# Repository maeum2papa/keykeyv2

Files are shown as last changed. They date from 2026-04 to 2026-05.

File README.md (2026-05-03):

# keykeyv2 제작 가이드

---

## 개발 계기
손목 터널 증후군 통증을 완화하기 위한 목적으로 개발
- 손목이 들리거나 꺽이는 걸 방지하기 위해 낮은 키보드를 사용
- 손목의 자연스러운 형태를 유지하기 위해 반으로 자름
- 개발자 주로 사용하는 키를 서로 가깝게 배치

---

## 키보드 특징

- **스플릿 키보드** (좌/우 분리형)
- **각 사이드 5행 6열** = 총 60키 (매트릭스)
- **왼쪽 사이드가 마스터**
- **방향키 4개**(다이렉트 핀, 5방향 네비게이션 스위치)
- **캡스락 LED** 1개
- **Vial-QMK** 사용 (GUI로 키맵 변경 가능)

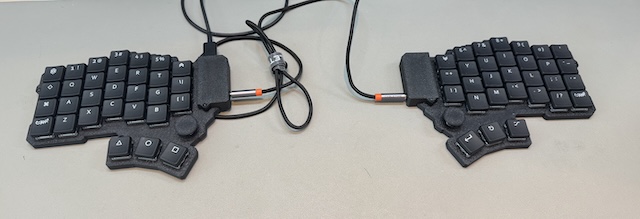
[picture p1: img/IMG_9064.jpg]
keykeyv2


---

## 필요 부품

### 🔲 프로세서
| 항목 | 수량 | 상세 |
|---|---|---|
| RP2040-Zero | 2개 | 좌/우 각 1개. 옆면 캐스텔레이티드(Castellated) 핀 납땜 계획. USB-C 내장 |

> ⚠️ 반드시 정품 구매

### ⌨️ 스위치 & 소켓
| 항목 | 수량 | 상세 |
|---|---|---|
| Kailh Choc v1 (1350) 스위치 | 60개 | 
| Choc v1 전용 핫스왑 소켓 | 60개 | 반드시 Choc v1 전용 규격 확인 (MX 소켓과 호환 안됨) |

### 🔵 다이오드
| 항목 | 수량 | 상세 |
|---|---|---|
| 1N4148W SMD 다이오드 | 60개 |

### 🕹️ 방향키 & 인코더
| 항목 | 수량 | 상세 |
|---|---|---|
| 5-Way 네비게이션 스위치 | 1개 | 상/하/좌/우/센터 클릭 지원 모델. PCB에 45도 회전 배치 권장 |

> ⚠️ 5방향 스위치를 정사각형으로 배치하면 대각 방향으로 눌러야 상하좌우 동작함.
> PCB 설계 시 반드시 **45도 회전(마름모) 배치** 권장

### 💡 상태 표시 LED
| 항목 | 수량 | 상세 |
|---|---|---|
| 3mm LED | 2개 | 각 사이드 1개. Caps Lock 활성 표시용 |
| 저항 330Ω | 2개 | LED 보호용. 각 사이드 GP28과 LED 사이에 직렬 연결 |

### 🔌 통신 & 연결
| 항목 | 수량 | 상세 |
|---|---|---|
| PJ-320A TRRS 잭 | 2개 | 반드시 4극 전용 (3극 사용 시 쇼트 위험) |
| 4극 TRRS 케이블 | 1개 | 양쪽 유선 연결용 |
| 저항 1kΩ | 2개 | GP0 ↔ TRRS Ring 사이 각 사이드 1개씩 (통신 보호용) |

---

## PCB 주문 제작
샘플 PCB를 제작 해주는 곳에서는 어디서든 가능 (JLC PCB, 샘플 PCB ...)

### 1. 거버 및 드릴 파일 다운로드
/last/keykeyv2.1_l.zip (왼쪽)
/last/keykeyv2.1_r.zip (오른쪽)

### 2. PCB 주문
keykeyv2.1_l.zip, keykeyv2.1_r.zip 파일을 업로드해서 주문

---

## 납땜

### 1. 납땜 위치
- 다이오드, 핫스왑 소켓 후면에 장착
- RP2024-zero, PJ-320A TRRS 잭, LED 앞면 장착

### 2. 다이오드 방향
- (|) 표시가 있는 방향이 양 사이드의 가운데를 향해야 함 (왼쪽 사이드에서는 오른쪽, 오른쪽 사이드에서는 왼쪽)

---

## 필요 프로그램 설치

### 1. 파일 다운로드
/last/keykeyv2_vial.uf2 다운로드

### 2. 각 사이드 마다 RP2024-zero 펌웨어 업로드
- 1. 모든 선 분리 후 USB만 단독으로 연결 (꼭 통신 케이블용 사용)
- 1. BOOT 버튼, RESET 버튼 동시에 누름
- 2. 1초 후 RESET 버튼에서 손때고 그 다음 1초 후 BOOT 버튼에서 손 땜
- 3. 외장 드라이버로 인식되면 keykeyv2_vial.uf2 파일 복사해서 저장
- 4. 자동으로 RP2024-zero 재부팅

---

## 작동 테스트

- 1. USB가 연결되지 않은 상태에서 TRRS선 연결
> ⚠️ USB가 연결된 상태에서 TRRS선 분리하면 고장남
- 2. USB 왼쪽 사이드에 연결
> 항상 왼쪽이 마스터

---

## 3D 프린터를 이용한 케이스 출력
/last/keykeyv2_case.3mf 다운로드 하여 출력

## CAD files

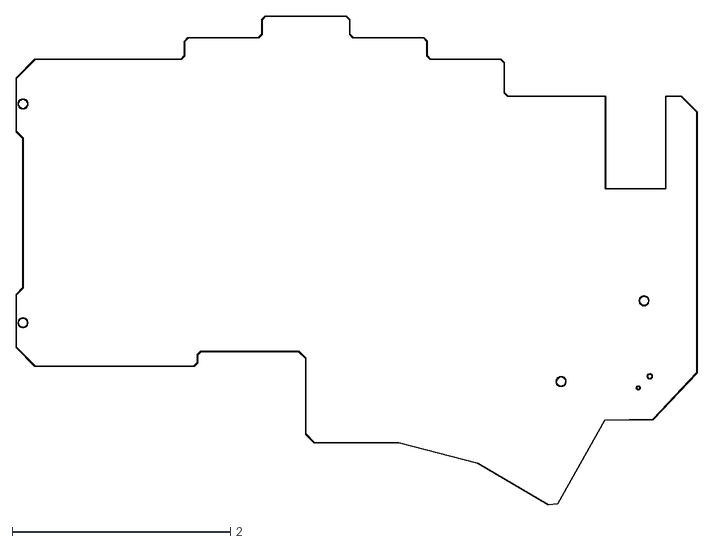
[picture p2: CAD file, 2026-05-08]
hardware/keykeyv2.1/print/keykeyv2.1-Edge_Cuts.dxf
6.24 x 4.48

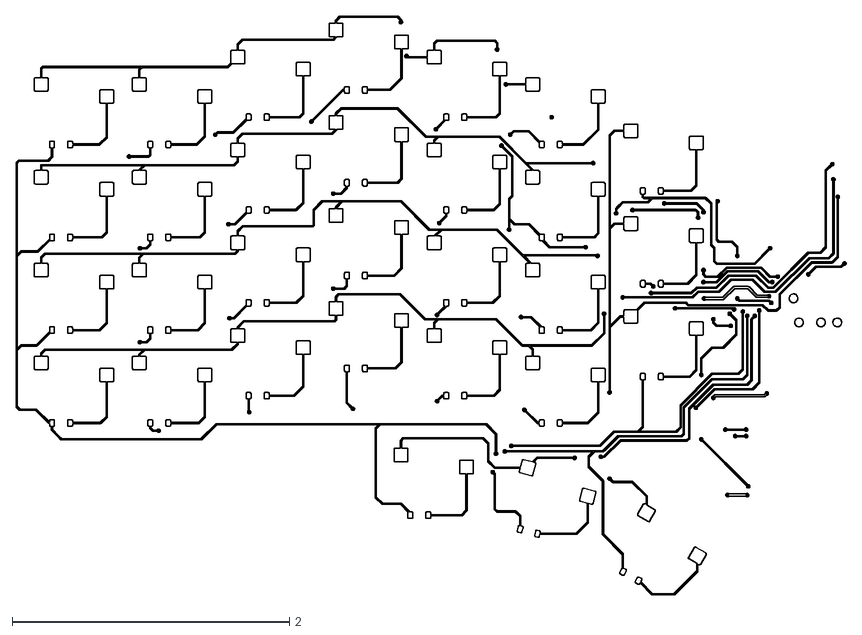
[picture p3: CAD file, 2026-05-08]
hardware/keykeyv2.1_r/print/keykeyv2.1-B_Cu.dxf
5.98 x 4.17

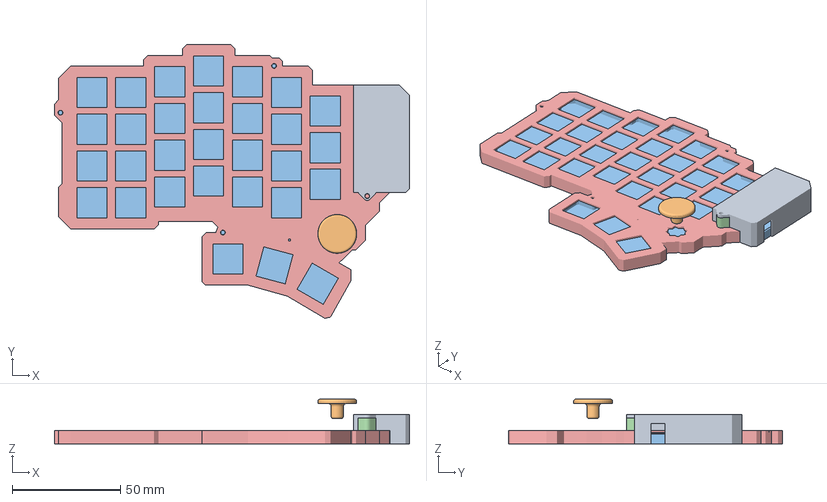
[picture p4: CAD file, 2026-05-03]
last/keykeyv2_case.3mf
164.3 x 126.7 x 20.7 mm
muc커버
네비게이션
본체
본체77
상판

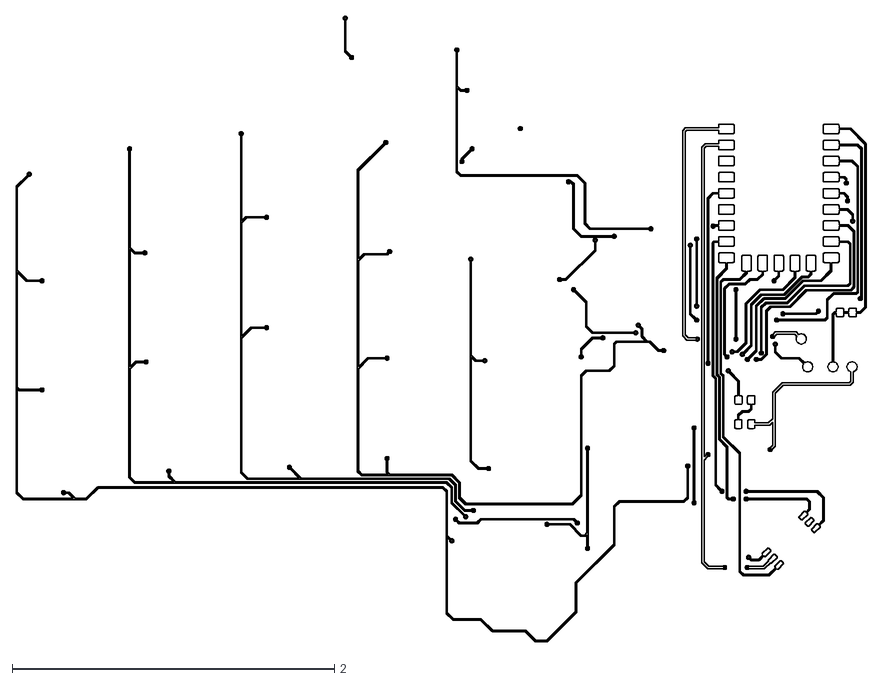
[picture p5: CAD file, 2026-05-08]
hardware/keykeyv2.1/print/keykeyv2.1-F_Cu.dxf
5.28 x 3.88

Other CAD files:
hardware/keykeyv2.1/print/keykeyv2.1-B_Mask.dxf
hardware/keykeyv2.1/print/keykeyv2.1-B_Paste.dxf
hardware/keykeyv2.1/print/keykeyv2.1-B_Silkscreen.dxf
hardware/keykeyv2.1/print/keykeyv2.1-F_Mask.dxf
hardware/keykeyv2.1/print/keykeyv2.1-F_Paste.dxf
hardware/keykeyv2.1/print/keykeyv2.1-F_Silkscreen.dxf
hardware/keykeyv2.1_r/print/keykeyv2.1-B_Mask.dxf
hardware/keykeyv2.1_r/print/keykeyv2.1-B_Paste.dxf
hardware/keykeyv2.1_r/print/keykeyv2.1-B_Silkscreen.dxf
hardware/keykeyv2.1_r/print/keykeyv2.1-F_Mask.dxf
hardware/keykeyv2.1_r/print/keykeyv2.1-F_Paste.dxf
hardware/keykeyv2.1_r/print/keykeyv2.1-F_Silkscreen.dxf

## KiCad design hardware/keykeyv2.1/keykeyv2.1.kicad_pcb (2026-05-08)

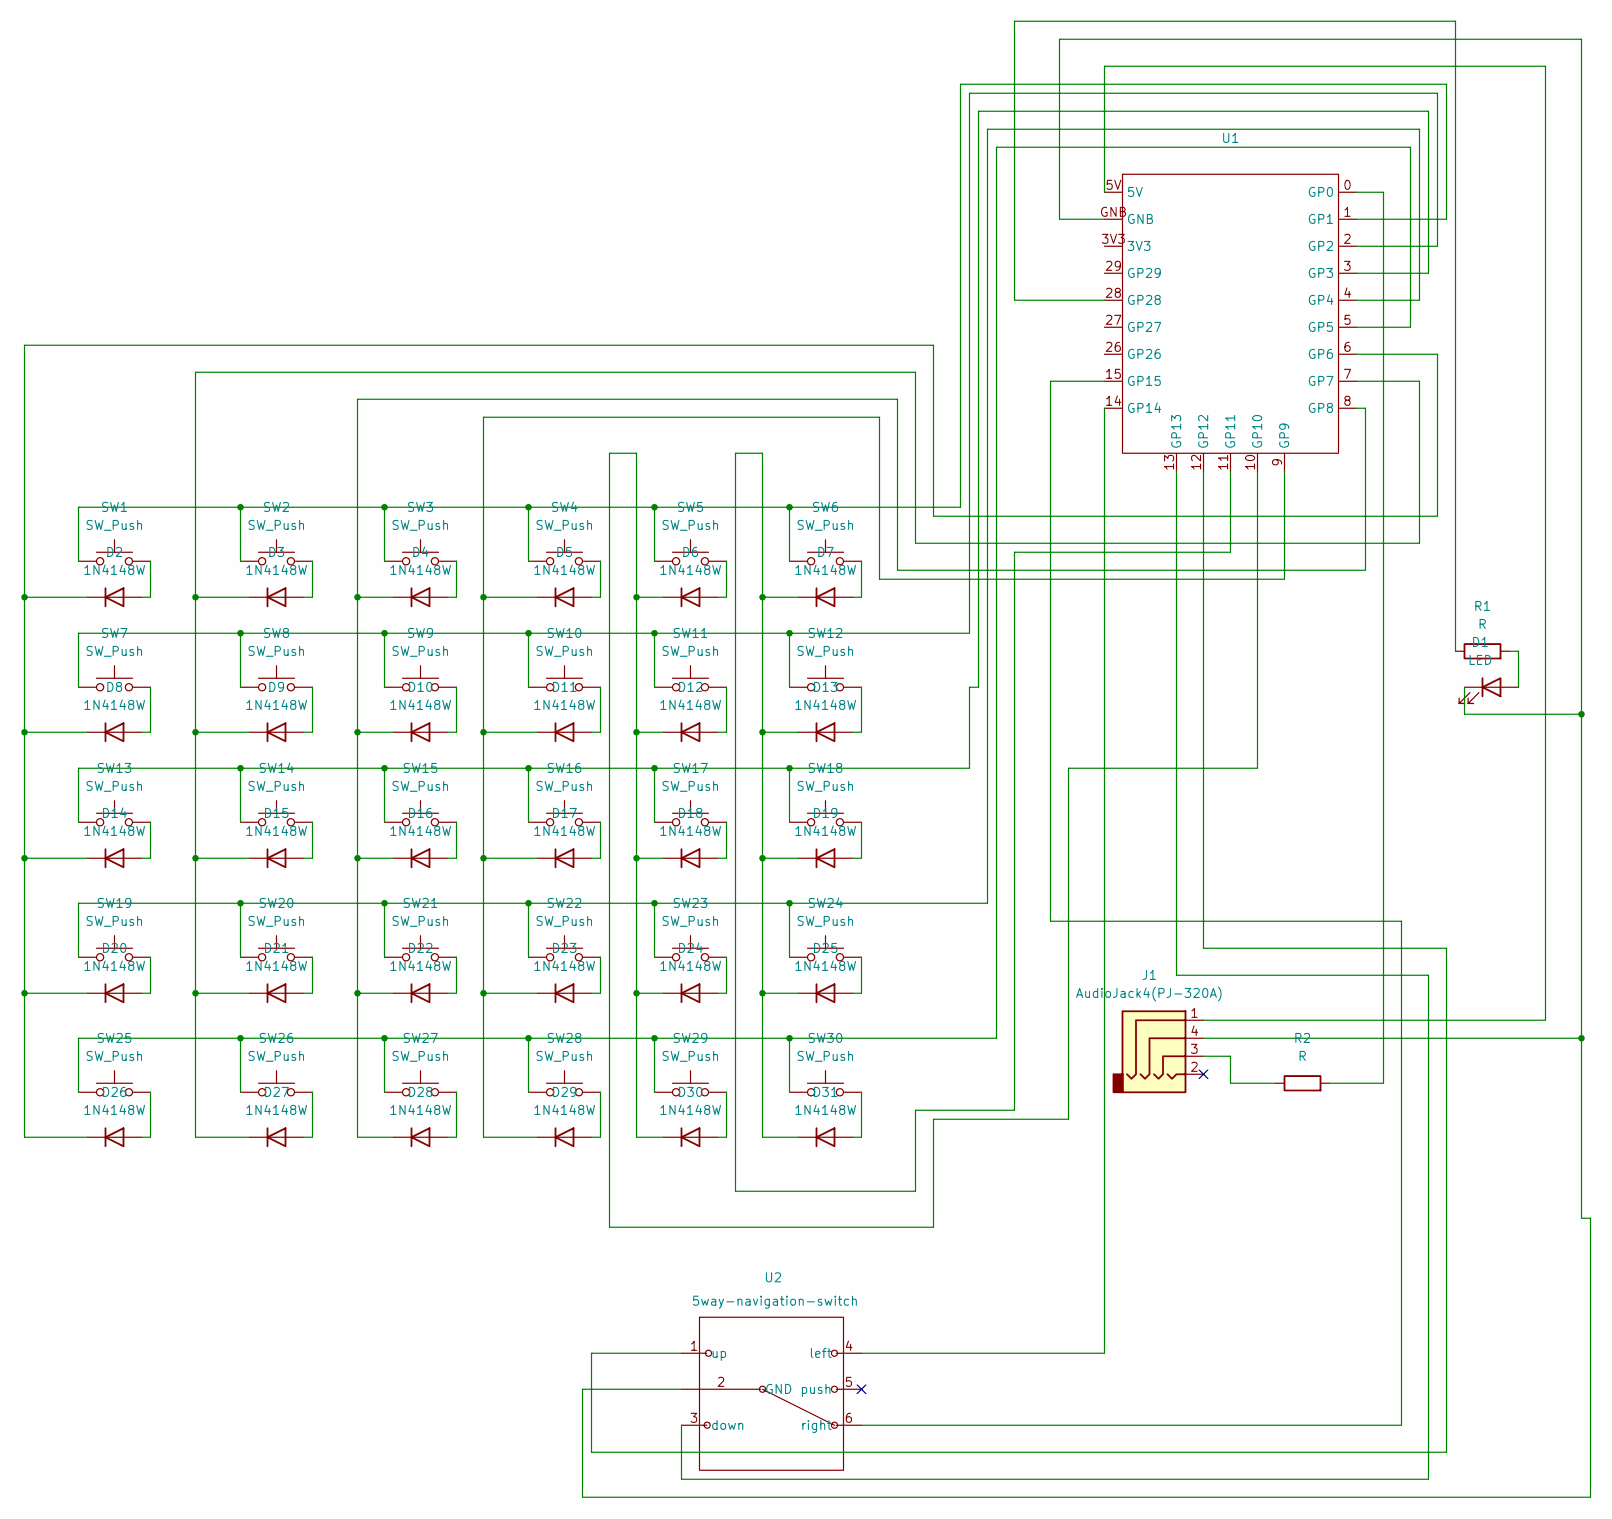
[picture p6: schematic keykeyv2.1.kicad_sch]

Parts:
D1: LED; LED_0805_2012Metric_Pad1.15x1.40mm_HandSolder
D2, D3, D4, D5, D6, D7, D8, D9, D10, D11, D12, D13, D14, D15, D16, D17, D18, D19, D20, D21, D22, D23, D24, D25, D26, D27, D28, D29, D30, D31: 1N4148W; D_SOD-123
J1: AudioJack4(PJ-320A); PJ-320A
R1, R2: R; R_0805_2012Metric_Pad1.20x1.40mm_HandSolder
SW1, SW2, SW3, SW4, SW5, SW6, SW7, SW8, SW9, SW10, SW11, SW12, SW13, SW14, SW15, SW16, SW17, SW18, SW19, SW20, SW21, SW22, SW23, SW24, SW25, SW26, SW27, SW28, SW29, SW30: SW_Push; SW_Hotswap_Kailh_Choc_V1V2_1.00u
U1: RP2040_Zero_Up_Mount
U2: 5way-navigation-switch

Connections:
unnamed: D1.2 (A), R1.2
unnamed: D1.1 (K), J1.4, U1.GNB, U2.2 (GND)
unnamed: D2.2 (A), SW1.2
unnamed: D3.2 (A), SW2.2
unnamed: D4.2 (A), SW3.2
unnamed: D5.2 (A), SW4.2
unnamed: D6.2 (A), SW5.2
unnamed: D7.2 (A), SW6.2
unnamed: D8.2 (A), SW7.2
unnamed: D9.2 (A), SW8.2
unnamed: D10.2 (A), SW9.2
unnamed: D4.1 (K), D10.1 (K), D16.1 (K), D22.1 (K), D28.1 (K), U1.8 (GP8)
unnamed: D11.2 (A), SW10.2
unnamed: D5.1 (K), D11.1 (K), D17.1 (K), D23.1 (K), D29.1 (K), U1.9 (GP9)
unnamed: D12.2 (A), SW11.2
unnamed: D6.1 (K), D12.1 (K), D18.1 (K), D24.1 (K), D30.1 (K), U1.10 (GP10)
unnamed: D13.2 (A), SW12.2
unnamed: D7.1 (K), D13.1 (K), D19.1 (K), D25.1 (K), D31.1 (K), U1.11 (GP11)
unnamed: D14.2 (A), SW13.2
unnamed: D2.1 (K), D8.1 (K), D14.1 (K), D20.1 (K), D26.1 (K), U1.6 (GP6)
unnamed: D15.2 (A), SW14.2
unnamed: D3.1 (K), D9.1 (K), D15.1 (K), D21.1 (K), D27.1 (K), U1.7 (GP7)
unnamed: D16.2 (A), SW15.2
unnamed: D17.2 (A), SW16.2
unnamed: D18.2 (A), SW17.2
unnamed: D19.2 (A), SW18.2
unnamed: D20.2 (A), SW19.2
unnamed: D21.2 (A), SW20.2
unnamed: D22.2 (A), SW21.2
unnamed: D23.2 (A), SW22.2
unnamed: D24.2 (A), SW23.2
unnamed: D25.2 (A), SW24.2
unnamed: D26.2 (A), SW25.2
unnamed: D27.2 (A), SW26.2
unnamed: D28.2 (A), SW27.2
unnamed: D29.2 (A), SW28.2
unnamed: D30.2 (A), SW29.2
unnamed: D31.2 (A), SW30.2
unnamed: J1.1, U1.5V
unnamed: J1.3, R2.1
unnamed: R2.2, U1.0 (GP0)
unnamed: SW1.1, SW2.1, SW3.1, SW4.1, SW5.1, SW6.1, U1.1 (GP1)
unnamed: SW7.1, SW8.1, SW9.1, SW10.1, SW11.1, SW12.1, U1.2 (GP2)
unnamed: SW13.1, SW14.1, SW15.1, SW16.1, SW17.1, SW18.1, U1.3 (GP3)
unnamed: SW19.1, SW20.1, SW21.1, SW22.1, SW23.1, SW24.1, U1.4 (GP4)
unnamed: SW25.1, SW26.1, SW27.1, SW28.1, SW29.1, SW30.1, U1.5 (GP5)
unnamed: U1.12 (GP12), U2.1 (up)
unnamed: U1.13 (GP13), U2.3 (down)
unnamed: U1.14 (GP14), U2.4 (left)
unnamed: U1.15 (GP15), U2.6 (right)
unnamed: R1.1, U1.28 (GP28)

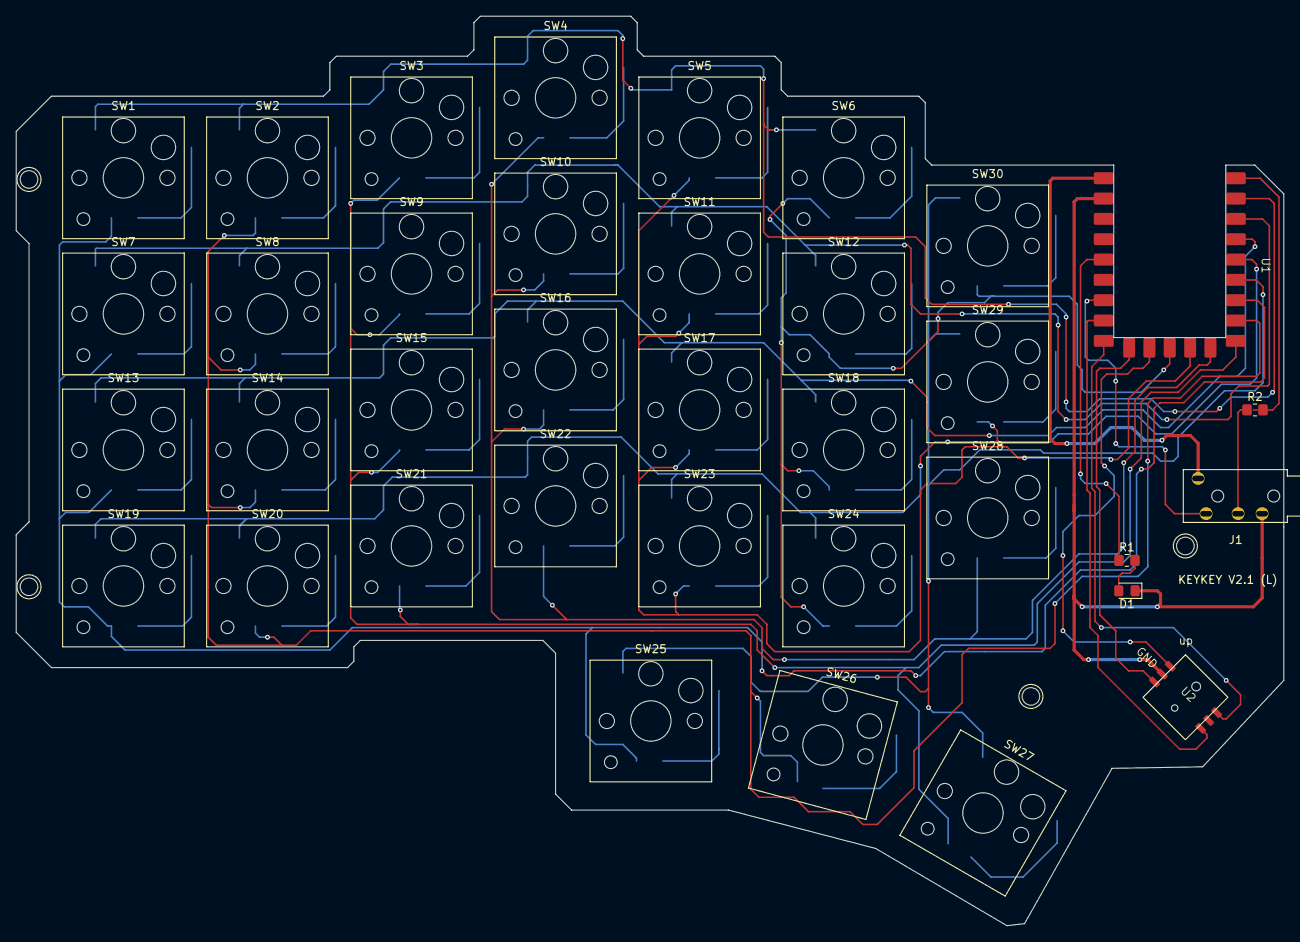
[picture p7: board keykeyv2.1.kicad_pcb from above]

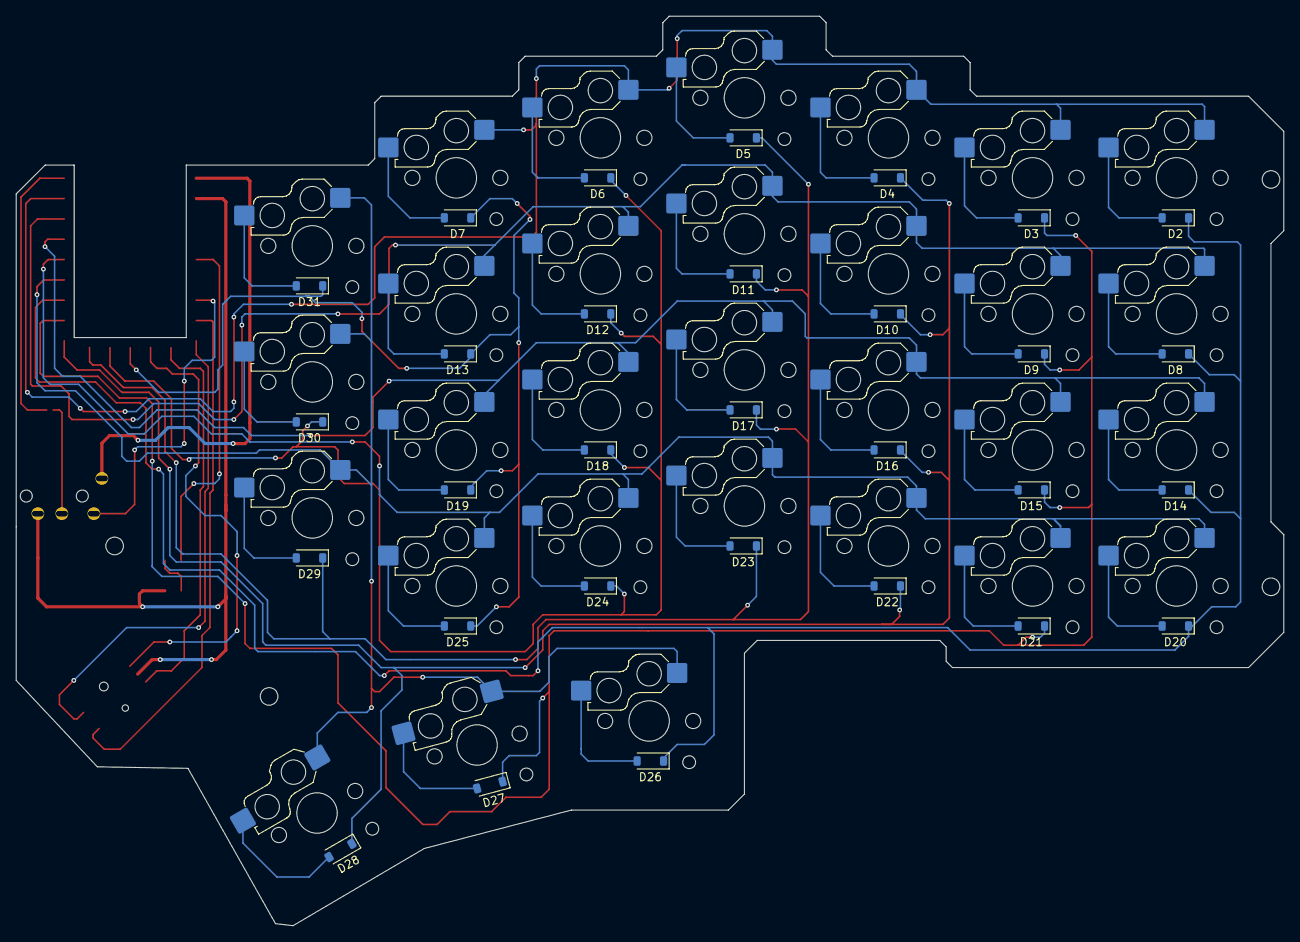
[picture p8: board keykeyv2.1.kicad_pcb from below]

Board: 2 copper layers, 158.4 x 113.6 mm, 66 parts (30 on the bottom side), 51 nets.

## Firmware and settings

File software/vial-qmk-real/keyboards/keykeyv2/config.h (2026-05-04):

#pragma once

// 항상 왼쪽에 USB를 연결하면 왼쪽=마스터, 오른쪽=슬레이브로 고정됨
// 하드웨어 핀 배선 불필요 (GP29 미사용)
#define MASTER_LEFT

// ── 대안: 특정 핀에 저항으로 핸드니스 감지 ──────────────────────────────
// 왼쪽 보드: 해당 핀에 풀업 저항 달기 (핀이 HIGH → 왼쪽)
// 오른쪽 보드: 해당 핀을 GND에 연결 (핀이 LOW  → 오른쪽)
// 사용 방법: MASTER_LEFT 주석 처리 후 아래 두 줄 활성화
//
// #define SPLIT_HAND_PIN GP29
// #define SPLIT_USB_DETECT
//
// (SPLIT_USB_DETECT 없이 SPLIT_HAND_PIN만 써도 되지만,
//  TRRS로 5V 공유 시 양쪽이 마스터로 오인할 수 있어 함께 쓰는 게 안전)
// ─────────────────────────────────────────────────────────────────────────
// 통신이 불안정할 때 슬레이브가 멈춰있지 않게 리셋/재시도
#define SPLIT_WATCHDOG_ENABLE

// Custom split RPC: sync 5-way nav GPIO state from the other half to master.
#define SPLIT_TRANSACTION_IDS_USER NAV5_GPIO_SYNC

#define DIRECT_KEY_LEFT   GP12
#define DIRECT_KEY_DOWN   GP13
#define DIRECT_KEY_UP     GP14
#define DIRECT_KEY_RIGHT  GP15

#define LED_CAPS_LOCK_PIN GP28
#define LED_PIN_ON_STATE  1

#define TAPPING_TERM 200

// Split serial (RP2040 vendor/Pio) - Full-duplex로 전환
// 기존 GP0 라인은 유지하고, 추가 라인 1개(GP26)를 더 써서 RX/TX를 분리한다.
// 배선은 "동일 핀끼리 직결" (GP0<->GP0, GP26<->GP26)로 하고,
// 마스터 쪽만 TX/RX 역할을 뒤집기 위해 SERIAL_USART_PIN_SWAP을 사용.
#define SERIAL_USART_FULL_DUPLEX
#define SERIAL_USART_PIN_SWAP
// 키보드 JSON(split.serial.pin=GP0)에서 SOFT_SERIAL_PIN이 정의되므로
// TX는 SOFT_SERIAL_PIN(GP0)을 그대로 사용하고, RX만 별도로 지정한다.
#define SERIAL_USART_RX_PIN GP26

// 안정성 우선으로 속도는 중간부터 시작(필요하면 올려도 됨)
#define SERIAL_USART_SPEED 57600

// ── Vial 필수 설정 ──────────────────────────────────────────────────────────
// python3 util/vial_generate_keyboard_uid.py 로 생성된 고유 ID
#define VIAL_KEYBOARD_UID {0x04, 0x68, 0x66, 0x41, 0x49, 0xED, 0xC3, 0x78}

// Vial 잠금 해제 콤보: 좌측 Ctrl(row=4,col=0) + 우측 Backspace(row=9,col=5)
#define VIAL_UNLOCK_COMBO_ROWS {4, 9}
#define VIAL_UNLOCK_COMBO_COLS {0, 5}
// ─────────────────────────────────────────────────────────────────────────────

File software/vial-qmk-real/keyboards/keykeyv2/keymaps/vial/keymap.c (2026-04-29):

#include QMK_KEYBOARD_H

#ifdef SPLIT_KEYBOARD
#    include "transactions.h"
#    include "split_common/split_util.h"
#endif

#ifdef CONSOLE_ENABLE
#    include "print.h"
#endif

typedef struct {
    uint8_t pressed_bits; // bit0..3 => GP12..GP15 (1 = pressed)
} nav5_gpio_state_t;

static nav5_gpio_state_t g_nav5_local  = {0};
static nav5_gpio_state_t g_nav5_remote = {0};

static nav5_gpio_state_t nav5_read_gpio_state(void) {
    nav5_gpio_state_t s = {0};
    if (!gpio_read_pin(GP12)) s.pressed_bits |= (1u << 0);
    if (!gpio_read_pin(GP13)) s.pressed_bits |= (1u << 1);
    if (!gpio_read_pin(GP14)) s.pressed_bits |= (1u << 2);
    if (!gpio_read_pin(GP15)) s.pressed_bits |= (1u << 3);
    return s;
}

#ifdef SPLIT_KEYBOARD
static void nav5_gpio_sync_slave(uint8_t initiator2target_buffer_size, const void *initiator2target_buffer, uint8_t target2initiator_buffer_size, void *target2initiator_buffer) {
    (void)initiator2target_buffer_size;
    (void)initiator2target_buffer;

    if (target2initiator_buffer_size >= sizeof(nav5_gpio_state_t) && target2initiator_buffer) {
        *(nav5_gpio_state_t *)target2initiator_buffer = g_nav5_local;
    }
}

void keyboard_post_init_user(void) {
    transaction_register_rpc(NAV5_GPIO_SYNC, nav5_gpio_sync_slave);

#    if defined(CONSOLE_ENABLE)
    debug_enable = true;
    uprintf("[init] left=%u master=%u\n", is_keyboard_left(), is_keyboard_master());
#    endif
}

void housekeeping_task_user(void) {
    // Always keep local state fresh so the slave handler can respond immediately.
    g_nav5_local = nav5_read_gpio_state();

#    if defined(CONSOLE_ENABLE)
    // 슬레이브에서도 nav 핀 상태 로깅 (눌렸을 때만)
    if (!is_keyboard_master() && g_nav5_local.pressed_bits != 0) {
        static uint8_t last_local = 0;
        if (g_nav5_local.pressed_bits != last_local) {
            last_local = g_nav5_local.pressed_bits;
            uprintf("[slave] local=0x%02X\n", g_nav5_local.pressed_bits);
        }
    }
#    endif

    if (!is_keyboard_master()) {
        return;
    }

    // Debug: print nav remote bits only when non-zero.
#    if defined(CONSOLE_ENABLE)
    static uint8_t last_remote_bits = 0;
    if (g_nav5_remote.pressed_bits != last_remote_bits) {
        last_remote_bits = g_nav5_remote.pressed_bits;
        uprintf("[nav] remote=0x%02X\n", g_nav5_remote.pressed_bits);
    }
#    endif

    // Poll the other half at a modest rate to avoid impacting key scanning.
    static uint32_t last_sync = 0;
    if (timer_elapsed32(last_sync) < 10) {
        return;
    }
    last_sync = timer_read32();

    nav5_gpio_state_t remote = {0};
    if (transaction_rpc_recv(NAV5_GPIO_SYNC, sizeof(remote), &remote)) {
        g_nav5_remote = remote;
#    if defined(CONSOLE_ENABLE)
        uprintf("[split] rpc ok remote=0x%02X\n", remote.pressed_bits);
#    endif
    } else {
        // Fail-safe: release any remote-generated presses if comms drop.
        g_nav5_remote.pressed_bits = 0;
#    if defined(CONSOLE_ENABLE)
        uprintf("[split] rpc FAIL\n");
#    endif
    }
}
#endif


void matrix_scan_user(void) {
#ifdef SPLIT_KEYBOARD
    if (!is_keyboard_master()) {
        return;
    }
#endif
    static bool key_pressed[4] = {false, false, false, false};

    // Combine nav input from both halves (master-local + remote).
    nav5_gpio_state_t local = nav5_read_gpio_state();
#ifdef SPLIT_KEYBOARD
    uint8_t bits = local.pressed_bits | g_nav5_remote.pressed_bits;
#else
    uint8_t bits = local.pressed_bits;
#endif

    // PCB 설계상 대각 스위치 2개가 동시에 눌려야 각 방향이 활성화됨
    // bit0=GP12, bit1=GP13, bit2=GP14, bit3=GP15
    bool p0 = bits & (1u << 0);
    bool p1 = bits & (1u << 1);
    bool p2 = bits & (1u << 2);
    bool p3 = bits & (1u << 3);

    // UP    = GP12 + GP14
    if (p0 && p2) {
        if (!key_pressed[0]) { register_code(KC_UP);      key_pressed[0] = true; }
    } else {
        if (key_pressed[0])  { unregister_code(KC_UP);    key_pressed[0] = false; }
    }

    // DOWN  = GP13 + GP15
    if (p1 && p3) {
        if (!key_pressed[1]) { register_code(KC_DOWN);    key_pressed[1] = true; }
    } else {
        if (key_pressed[1])  { unregister_code(KC_DOWN);  key_pressed[1] = false; }
    }

    // LEFT  = GP12 + GP13
    if (p0 && p1) {
        if (!key_pressed[2]) { register_code(KC_LEFT);    key_pressed[2] = true; }
    } else {
        if (key_pressed[2])  { unregister_code(KC_LEFT);  key_pressed[2] = false; }
    }

    // RIGHT = GP14 + GP15
    if (p2 && p3) {
        if (!key_pressed[3]) { register_code(KC_RIGHT);   key_pressed[3] = true; }
    } else {
        if (key_pressed[3])  { unregister_code(KC_RIGHT); key_pressed[3] = false; }
    }
}

#ifdef CONSOLE_ENABLE
bool process_record_user(uint16_t keycode, keyrecord_t *record) {
    if (record->event.pressed) {
        uprintf("[key] kc=0x%04X row=%u col=%u\n", keycode, record->event.key.row, record->event.key.col);
    }
    return true;
}
#endif


const uint16_t PROGMEM keymaps[][MATRIX_ROWS][MATRIX_COLS] = {
    [0] = LAYOUT(
        KC_ESC,  KC_1,    KC_2,    KC_3,    KC_4,    KC_5,
        KC_TAB,  KC_Q,    KC_W,    KC_E,    KC_R,    KC_T,
        KC_LALT, KC_A,    KC_S,    KC_D,    KC_F,    KC_G,
        KC_LSFT, KC_Z,    KC_X,    KC_C,    KC_V,    KC_B,
        KC_LCTL, KC_CAPS, KC_SPC,  KC_LBRC, KC_BSLS, KC_TRNS,

        KC_6,    KC_7,    KC_8,    KC_9,    KC_0,    KC_GRV,
        KC_Y,    KC_U,    KC_I,    KC_O,    KC_P,    KC_MINS,
        KC_H,    KC_J,    KC_K,    KC_L,    KC_SCLN, KC_QUOT,
        KC_N,    KC_M,    KC_COMM, KC_DOT,  KC_SLSH, KC_RSFT,
        KC_TRNS, KC_EQL,  KC_RBRC, KC_ENT,  KC_BSPC, KC_RALT
    ),
    [1] = LAYOUT(
        KC_GRV,  KC_F1,   KC_F2,   KC_F3,   KC_F4,   KC_F5,
        _______, _______, _______, _______, _______, _______,
        _______, _______, _______, _______, _______, _______,
        _______, _______, _______, _______, _______, _______,
        _______, _______, _______, _______, _______, _______,

        KC_F6,   KC_F7,   KC_F8,   KC_F9,   KC_F10,  KC_DEL,
        _______, _______, _______, KC_MINS, KC_EQL,  _______,
        _______, _______, _______, KC_LBRC, KC_RBRC, _______,
        _______, _______, _______, _______, _______, _______,
        _______, _______, KC_HOME, KC_PGDN, KC_PGUP, KC_END
    ),
    [2] = LAYOUT(
        _______, _______, _______, _______, _______, _______,
        _______, _______, _______, _______, _______, _______,
        _______, _______, _______, _______, _______, _______,
        _______, _______, _______, _______, _______, _______,
        QK_BOOT, _______, _______, _______, _______, _______,

        _______, _______, _______, _______, _______, _______,
        _______, _______, _______, _______, _______, _______,
        _______, _______, _______, _______, _______, _______,
        _______, _______, _______, _______, _______, _______,
        _______, _______, _______, _______, _______, _______
    ),
};

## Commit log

2026-05-02 업데이트
    [keykeyv2.1-B_Cu.gbr, keykeyv2.1-B_Mask.gbr, keykeyv2.1-B_Paste.gbr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]
2026-05-02 이미지 업로드
2026-05-03 3D 프린터 케이스 출력 파일 업데이트
    [keykeyv2_case.3mf]
2026-05-08 kicad 파일 좌우 분리
    [keykeyv2.1-B_Cu.dxf, keykeyv2.1-B_Mask.dxf, keykeyv2.1-B_Paste.dxf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]
